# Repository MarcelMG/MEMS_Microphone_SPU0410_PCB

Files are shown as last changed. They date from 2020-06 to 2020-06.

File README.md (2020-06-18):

# MEMS_Microphone_SPU0410_PCB
A PCB design for prototyping the Knowles SPU0410 MEMS Ultrasonic Microphone

This is a PCB designed for the Knowles SPU0410LR5H MEMS Microphone [(datasheet link)](https://www.knowles.com/docs/default-source/model-downloads/spu0410lr5h-qb-revh.pdf).
The SPU0410 microphone has the characteristic of beeing sensitive well beyond the audible audio spectrum in the ultrasonic (up to 80kHz and probably above).
Sadly, the microphone is in really tiny package with solder pads beneath the package, which makes it highly unsuited for hobbyists or prototyping.
The PCB uses a special footprint that still allows to solder the microphone by hand, the idea for this comes from hackaday.io user [Alan Green](https://hackaday.io/alang), you can read more about it [here](https://hackaday.io/project/165081-blue-board-01/details). I recorded the hand soldering process, you can watch a video of it [here](https://vimeo.com/430343841).
The input port of the microphone is on the backside of the PCB.
The design additionally includes a dual opamp that provides a buffered virtual ground (Vcc/2) as well as +20dB of flat gain. The recommended power supply range is between 1.8V and 3.6V.

<p float="left">
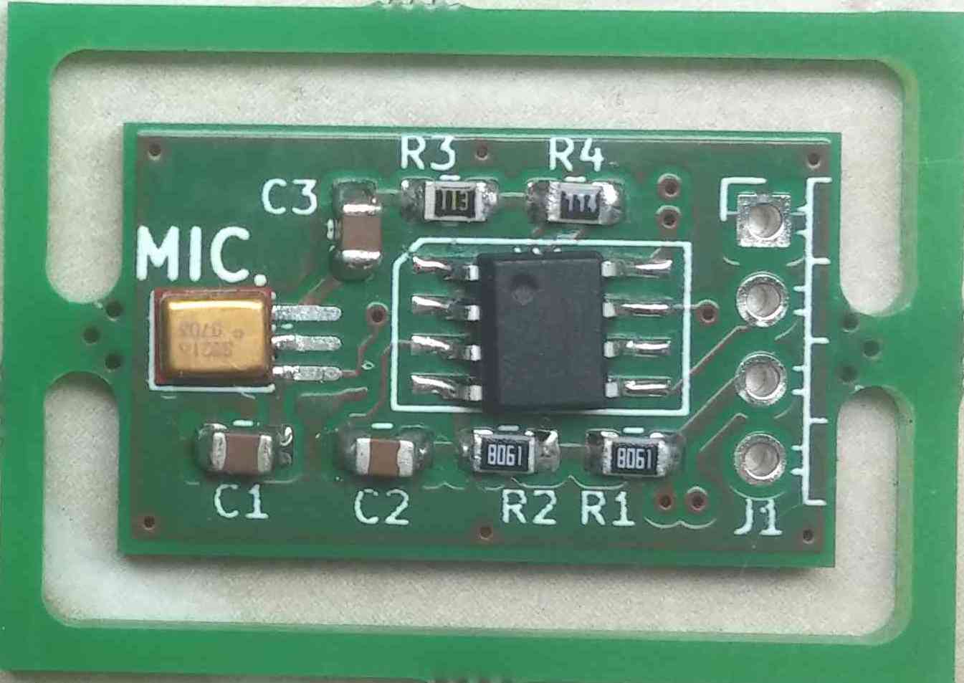
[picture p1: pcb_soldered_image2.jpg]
  
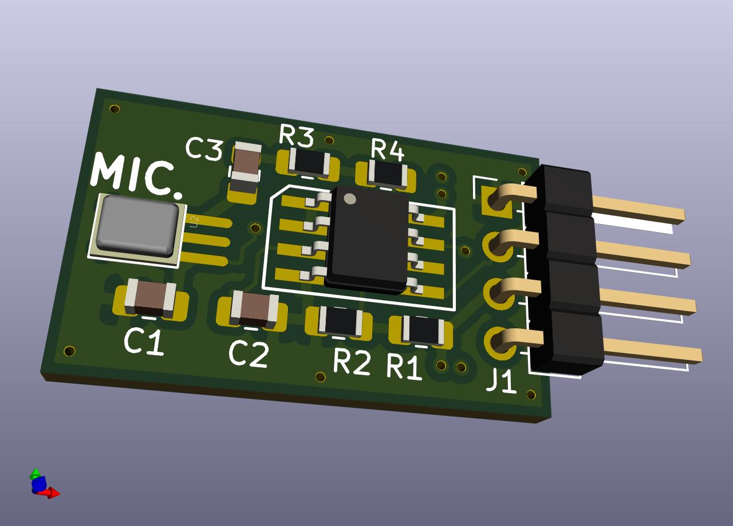
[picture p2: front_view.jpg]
   
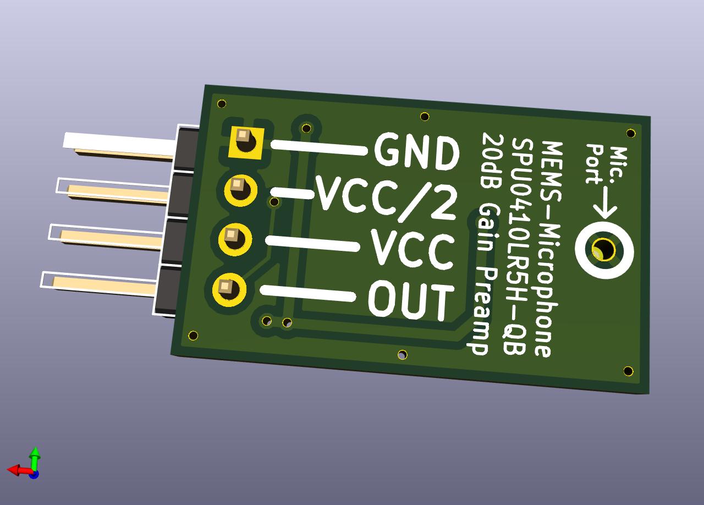
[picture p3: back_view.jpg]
  
</p>

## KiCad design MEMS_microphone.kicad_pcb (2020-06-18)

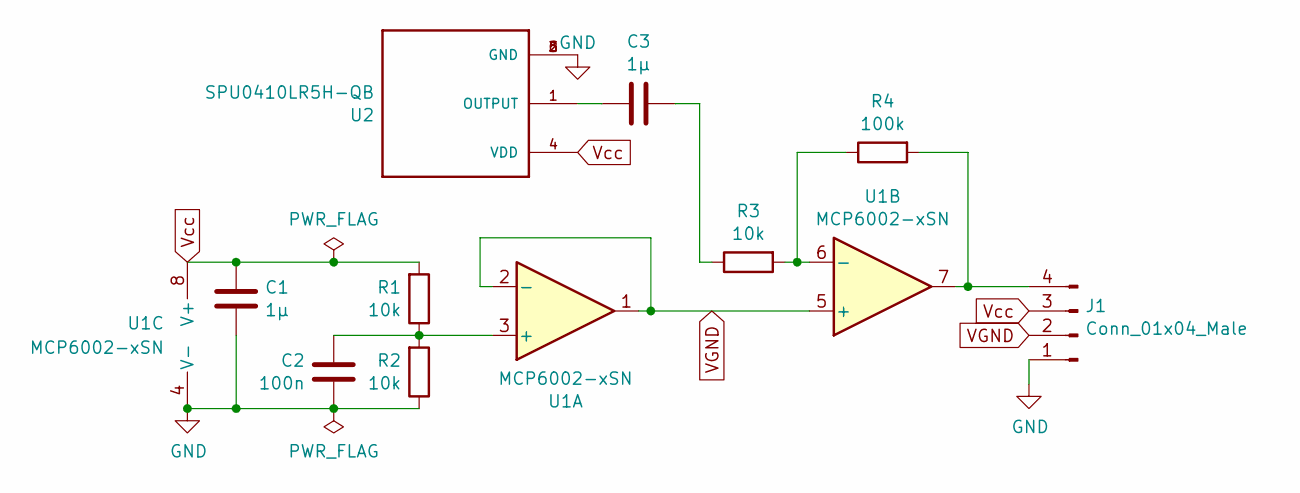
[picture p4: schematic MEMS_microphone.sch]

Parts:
C1, C3: 1µ; C_0805_2012Metric_Pad1.15x1.40mm_HandSolder
C2: 100n; C_0805_2012Metric_Pad1.15x1.40mm_HandSolder
J1: Conn_01x04_Male; PinHeader_1x04_P2.54mm_Horizontal
R1, R2, R3: 10k; R_0805_2012Metric_Pad1.15x1.40mm_HandSolder
R4: 100k; R_0805_2012Metric_Pad1.15x1.40mm_HandSolder
U1: MCP6002-xSN; SOIC-8_elongated_pads_MARCEL
U2: SPU0410LR5H-QB; SPU0410LR5H-QB_HANDSOLDER

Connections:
GND: C1.2, C2.1, J1.1, R2.1, U1.4 (V-), U2.2 (GND), U2.3 (GND), U2.5 (GND), U2.6 (GND)
unnamed: C2.2, R1.1, R2.2, U1.3 (+)
unnamed: C3.1, U2.1 (OUTPUT)
unnamed: C3.2, R3.1
unnamed: J1.4, R4.2, U1.7
unnamed: R3.2, R4.1, U1.6 (-)
VGND: J1.2, U1.1, U1.2 (-), U1.5 (+)
Vcc: C1.1, J1.3, R1.2, U1.8 (V+), U2.4 (VDD)

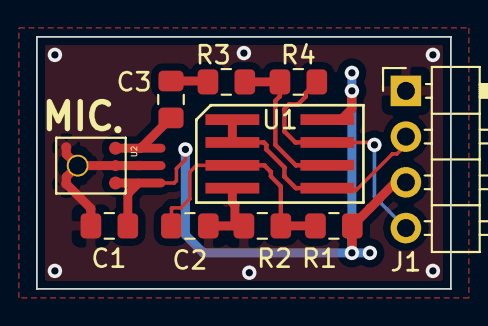
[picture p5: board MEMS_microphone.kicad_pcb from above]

Board: 2 copper layers, 23.0 x 14.0 mm, 10 parts (0 on the bottom side), 8 nets.

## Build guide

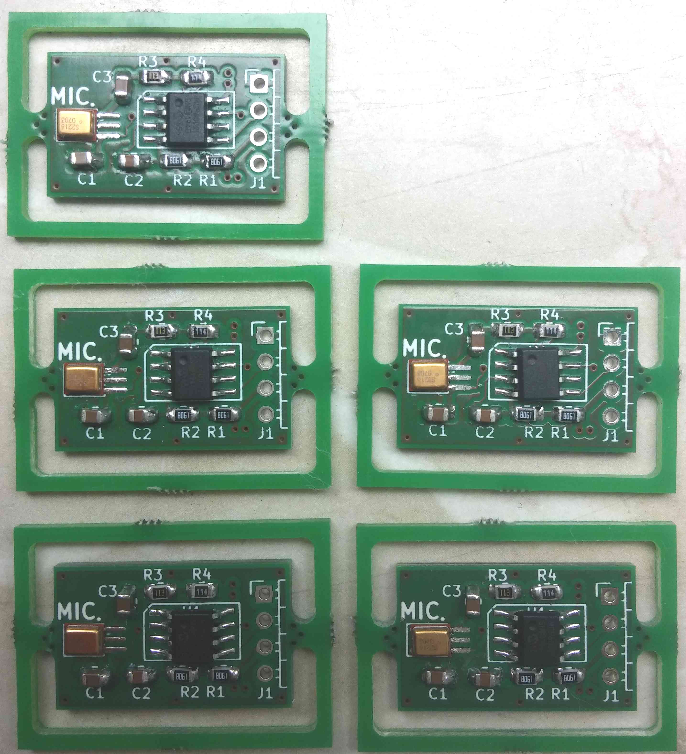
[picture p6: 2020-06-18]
pcb_soldered_image.jpg
